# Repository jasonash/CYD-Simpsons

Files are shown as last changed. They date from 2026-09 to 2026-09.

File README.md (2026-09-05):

# CYD-Simpsons

Turn a Cheap Yellow Display (ESP32-2432S028R) into a tiny, always-on retro
television that plays The Simpsons from a microSD card.

It is deliberately TV-like, not media-player-like: you turn it on and something
is already playing. Tap to change the channel with a burst of static. A
randomizer decides what airs. Fake commercials and interference are planned.

You supply your own legally obtained episodes. This project ships no media.

## Status

Phase 0 (feasibility spike). Bring-up firmware and a converter exist; real-time
playback is not implemented yet. See `firmware/README.md`.

## Hardware

- ESP32-2432S028R "CYD": ESP32-WROOM-32, 2.8" ILI9341 320x240, XPT2046 touch, microSD, speaker header. No PSRAM, which shapes the whole design.
- microSD card, A1 class recommended, FAT32.
- Small speaker on the onboard amp header.

## Layout

```
firmware/    PlatformIO project for the ESP32
converter/   Python + ffmpeg tool that makes playable AVI files
tools/       Test media generator, helper scripts
```

## Wiring

See `firmware/WIRING.md` for the external I2S amplifier, speaker, power and
touch pins.

## Quick start

1. `cd firmware && pio run -t upload && pio device monitor` to flash the bring-up sketch.
2. `tools/make_test_media.sh 30` to generate a test clip, copy it to the SD root.
3. `converter/cyd_convert.py --out /Volumes/SD/ episodes/` to convert real episodes.
   Sources are scaled to fill the screen and centre-cropped by default
   (`--fit cover`); pass `--fit contain` for letterbox/pillarbox instead.

## Media format

MJPEG video (320x240, 15 fps by default) with 16-bit mono PCM audio in an AVI
container. Roughly 230 MB per 22 minute episode.

## License

Apache 2.0. See LICENSE.

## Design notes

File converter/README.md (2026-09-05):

# CYD-Simpsons converter

Desktop-side tool that transcodes episodes into the only format the ESP32 can
play in real time: MJPEG video + 16-bit mono PCM audio in an AVI.

Requires ffmpeg and ffprobe (`brew install ffmpeg`). Python 3.10+, no other dependencies.

```sh
./cyd_convert.py --preset balanced --out /Volumes/SDCARD/channels/1 ~/Videos/Simpsons/S05/
```

| Preset | Video | Audio | Use |
|---|---|---|---|
| quality  | 320x240 @ 20 fps, q8 | 22050 Hz | Smoothest; about 1% dropped frames in busy scenes |
| balanced | 320x240 @ 15 fps, q8 | 22050 Hz | Default. Fills the panel with decode headroom |
| smallest | 320x240 @ 15 fps, q12  | 22050 Hz | Smaller files, softer picture |

All presets fill the 320x240 panel. Sources are scaled to cover the canvas and
centre-cropped by default (`--fit cover`); `--fit contain` letterboxes instead.
`--fps N` and `--qscale N` override a preset. Each output gets a `.json`
sidecar with duration, frame count, size, and average bitrate.

Expect roughly 10 MB per minute at the default preset (a 22 minute episode is
about 230 MB).

Use `--dry-run` to print the ffmpeg commands without running them.

Planned (later phases): per-frame size clamp, seek tables, library manifest,
full SD card layout builder.

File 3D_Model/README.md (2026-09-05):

# Simpsons TV enclosure (OpenSCAD)

A cartoon-accurate television case for the CYD-Simpsons player. Parametric OpenSCAD
source, one STL per printed part, one color per part.

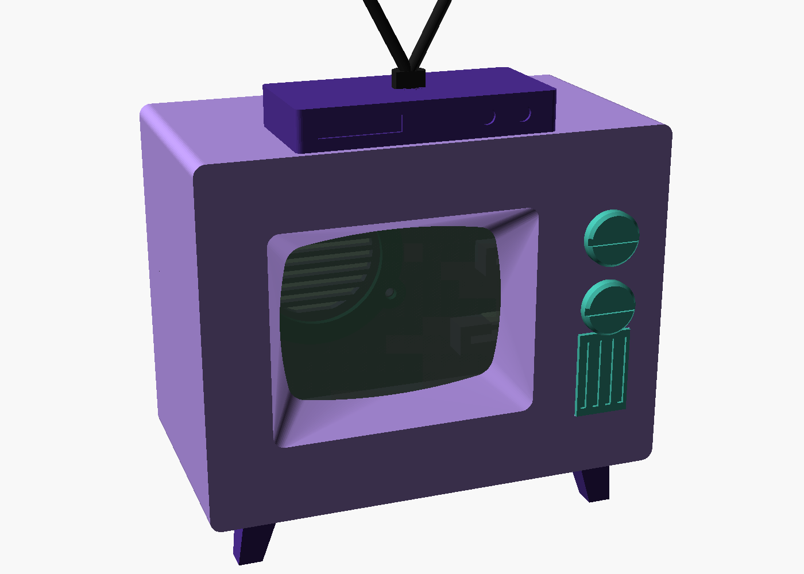
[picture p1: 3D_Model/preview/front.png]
front

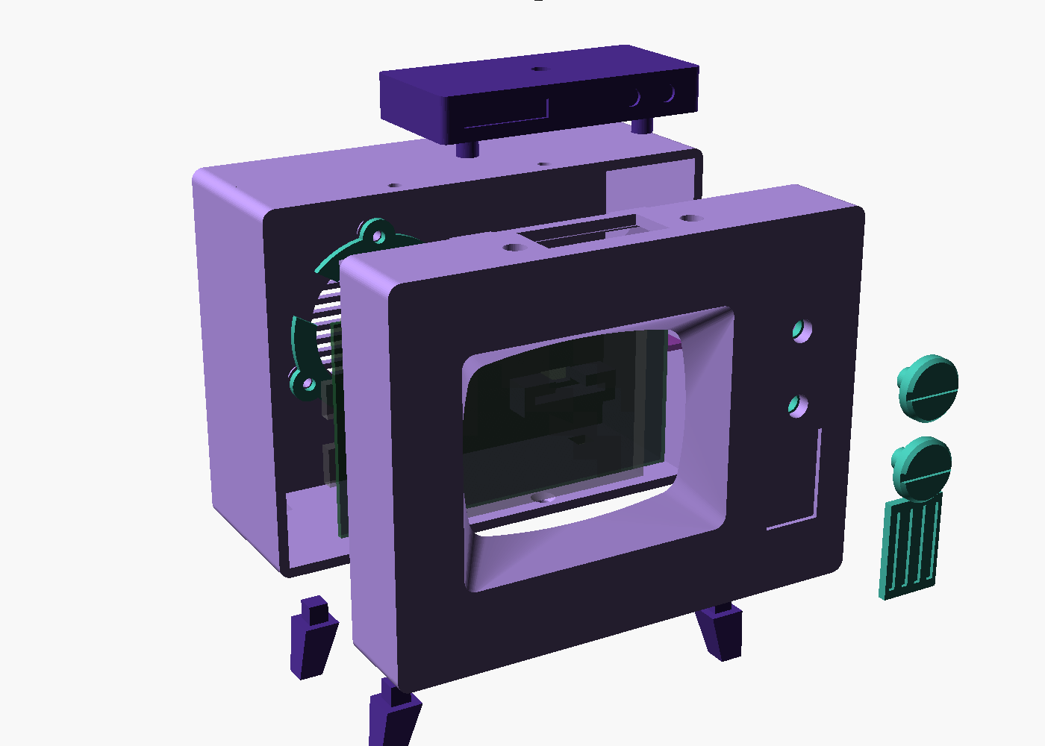
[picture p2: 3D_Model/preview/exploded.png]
exploded


## Files

| File | Purpose |
|---|---|
| `simpsons_tv.scad` | The whole model. All dimensions are parameters at the top. |
| `export.sh` | Renders every part to `stl/` and refreshes `preview/`. |
| `stl/*.stl` | Print-ready parts, already in print orientation. |
| `preview/*.png` | Assembly renders. |

Render one part by hand:

```bash
/Applications/OpenSCAD-2021.01.app/Contents/MacOS/OpenSCAD -D 'part="knob"' -o stl/knob.stl simpsons_tv.scad
```

Open `simpsons_tv.scad` in OpenSCAD for the assembly view. The variables at the top
of the file control it (Window > Customizer shows them as checkboxes and sliders,
then press F5):

- `explode = 20` pulls the assembly apart.
- `show_front_shell`, `show_rear_shell`, `show_knobs`, `show_grill`, `show_legs`,
  `show_set_top_box`, `show_speaker_clamp`, `show_components` hide parts.
- `cut_x = 60` slices the model to show a section through the middle. `cut_y` and
  `cut_z` do the same on the other axes. `-1` turns a cut off.
- `part = "plate"` shows every part in print orientation.
- `export.sh` runs `check_stl.py` on every STL it writes and fails if any part is not
  a single closed shell. Run it by hand on any STL to find floating geometry: it lists
  each disconnected shell with its bounding box in print coordinates.

## Parts and colors

| STL | Qty | Color | Print orientation | Notes |
|---|---|---|---|---|
| `front_shell` | 1 | lavender, bezel painted dark purple | face down | No supports. The screen bezel is part of the shell: a pocket that lofts from a rectangular opening at the face down to a CRT-shaped window, painted after printing. Holds the CYD, the button carrier and the grill. The lip and screw tabs grow from a chamfered step inside the wall. |
| `rear_shell` | 1 | lavender | back panel down | No supports. Speaker vents, speaker bosses, amp and USB pockets, USB-C opening. |
| `knob` | 2 | teal or green | face down | Groove across the face is the cartoon indicator bar. |
| `knob_keeper` | 2 | any | flat | Press or glue onto the knob stem behind the front plate. |
| `button_carrier` | 1 | any | flat | Carries the two 6 x 6 mm tactile switches. |
| `grill` | 1 | teal | slots up | Decorative. Glue into the front recess. |
| `leg_l`, `leg_r` | 2 each | dark purple | on its side | Square pegs into the floor. Glue. |
| `set_top_box` | 1 | dark purple | upside down | Pegs into the roof. Not glued: it covers the microSD hatch and the two roof screws. |
| `antenna` | 1 | black | flat back down | Pegs into the top of the set-top box. |
| `speaker_clamp` | 1 | any | flat | C-ring that holds the speaker flange against the back panel. |

Cartoon colors: the body is lavender purple, the screen bezel is a very dark
purple, the legs and set-top box a deeper purple, the knobs and grill teal-green,
the antenna black. Hex values used in the preview are listed at the top of the SCAD.

The bezel is painted, not printed separately: mask along the crease where the flat
face meets the slope and paint the sloped pocket dark. The other community builds
of this TV do the same.

## Hardware

All screws are M3, driven into printed 3.0 mm pilot holes (self-tapping into PLA or PETG).
Printed holes come out undersize, so 3.0 mm in the model is what an M3 actually taps
into; the first print at 2.5 mm snapped a standoff off the plate when the screw went in.
Every standoff and boss is 7 mm across with a flared base for the same reason.

| Use | Qty | Screw |
|---|---|---|
| CYD to front shell standoffs | 4 | M3 x 6 pan head |
| Button carrier to front shell | 2 | M3 x 6 pan head |
| Rear shell to front shell tabs (roof and floor) | 4 | M3 x 6 or x 8 countersunk |
| Speaker clamp | 3 | M3 x 6 pan head |

Other parts: 2 x 6 x 6 x 5 mm through-hole tactile switches, the 40 mm speaker,
the PAM8302 amp, the USB-C breakout, wire, and a little CA glue.

## Layout

- Front 118 x 90 mm, body 65 mm deep, legs add 14 mm. Aspect ratio follows the cartoon.
- The CYD is mounted with its USB ports on the left and the microSD slot on the top
  edge, i.e. rotated 180 degrees from the usual drawing. The firmware must use display
  rotation 3 instead of 1 (and the touch map flips with it).
- The microSD card is reached through a hatch in the roof, hidden by the set-top box.
- The speaker fires rearward through vents in the back panel. The front grill is decorative.
- The USB-C breakout (22 x 17 x 2 mm, connector on the long edge) sits in a slide-in
  pocket on the back panel with its port through the panel. Wire VBUS and GND to the
  CYD's 5 V and GND pins. Power only.
- The window is positioned from the CYD, not the other way round: the board sits
  `cyd_wall_gap` from the left wall and the window centre is `cyd_screen_cx` to the
  right of the board edge. Changing the screen offset moves the window, never the board.
- The window is the old-television outline: `win_w` x `win_h` (57 x 43) measured at
  the middle of each edge, every edge bowing outward by `win_bulge` (2.5) past the
  corner line, corners rounded `win_r` (5). It is cut to the panel's active picture
  area, not to the 69 x 50 glass, so the glass, its driver strip and the module edge
  all sit behind the bezel, and a small centring error hides a sliver of picture
  instead of showing the edge of the module. The picture's own corners are clipped a
  little by the bulge, which is how a CRT looked.
- The opening at the face is a plain rectangle (`bez_inset` 5 outside the window at
  the edge middles, corner radius `bez_r` 3). The pocket is a loft between the two
  outlines, `bez_slope` (10) deep, so it is steep along the edges (63 degrees) and
  sweeps out shallow at the corners (about 40 degrees, the shallowest spot of the
  face-down print; the SCAD echoes both angles). A straight tube then continues to
  `bez_depth` and stops `glass_gap` above the glass. Do not close that gap: the touch
  panel is resistive and the bezel would register as a touch.
- The amp sits in a second pocket above the USB pocket. Its own holes are only 2 mm,
  so it is held by the pocket, not screws.
- The rear shell slides over a lip on the front shell and is held by four countersunk
  M3 screws through the roof and floor into tabs on the lip. The roof screws are under
  the set-top box, the floor screws are out of sight.

## Assembly order

1. Solder the two tactile switches to the button carrier (pins through the four holes
   per switch, plungers facing the front). Wire them to CYD GPIOs.
2. Screw the CYD to the four standoffs in the front shell, screen toward the plate.
3. Screw the button carrier to its two bosses.
4. Push each knob stem through its hole from the front and press a keeper onto the stem
   from behind. Leave about 0.3 mm of play so the knob can travel. Glue the keeper.
5. Glue the grill into its recess.
6. Screw the speaker into the rear shell with the clamp ring, solder tabs in the notch.
   Slide the amp and USB breakout into their pockets and wire everything.
7. Push the rear shell onto the front shell lip and drive the four countersunk screws.
8. Glue the legs into the floor. Push the set-top box onto its roof pegs and the antenna
   into the box.

## Verify before printing the shells

These numbers came from drawings, not from measuring the actual parts. Print the small
parts first, then check these against your hardware and adjust the parameters:

- `cyd_glass` (4.5 mm): height of the CYD glass above the PCB front face. Two boards measured
  3.9 and 4.5 mm; the model uses the taller one. Sets the standoff height. Re-check on any other board.
- `cyd_screen_cx` (45.5 mm): centre of the active picture area from the board's USB
  edge. Measured on the board 2026-09-05: 16 mm of bezel on the USB side, 59 mm of
  picture, 11 mm on the far side (the earlier gap test on the first print gave 45.9,
  within 0.4 mm). `cyd_screen_cz` does the same vertically; measured centred, 2.5 mm
  top and bottom. The glass itself runs from 8 to 77 mm on the board (`cyd_glass_x0`).
- `usb_pcb_w`, `usb_pcb_l`, `usb_pcb_t`, `usb_conn_h`, `usb_conn_stick`: the USB-C
  breakout, measured 2026-09-04 as 22 x 17 x 2.0 mm, 5.0 mm overall, connector
  overhanging the edge by 1.5 mm. The connector body rides on the PCB, so the port
  opening is cut the full depth of the pocket's top rail.
- `spk_notch_angle` (150 degrees): rotate the speaker so its solder tabs sit in the
  clamp notch. The three bosses are 120 degrees apart, so any orientation works.
- Tactile switch height `sw_h` (5.0 mm). The switch travel is about 0.25 mm, and the knob
  stem rests on the plunger with 0.1 mm of pretravel.

The reference STEP file in `reference_materials/` is for the 3.5-inch CYD (ER-TFT035),
not the 2.8-inch board this project uses, so it was not used for dimensions.

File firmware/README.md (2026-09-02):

# CYD-Simpsons firmware

PlatformIO project targeting the ESP32-2432S028R Cheap Yellow Display.

## Build and flash

Install the PlatformIO CLI (`pipx install platformio`) or the VS Code extension, then:

```sh
cd firmware
pio run -e cyd_2432s028r -t upload
pio device monitor
```

If the screen stays white or colors are wrong, try the ST7789 clone profile:

```sh
pio run -e cyd_2432s028r_st7789 -t upload
```

## Layout

```
src/
  main.cpp        Phase 0 bring-up sketch (display, SD benchmark, touch, DAC tone)
  boards/         Board profiles. All GPIO numbers live here.
  player/         AVI parse, JPEG strip decode, A/V sync      (Phase 0/1)
  channels/       Scheduler, shuffle bag, broadcast position   (Phase 1/2)
  effects/        Static, fuzz, channel OSD                    (Phase 1/3)
  web/            HTTP server, JSON API, embedded assets       (Phase 4)
```

## Phase 0 bring-up sketch

On boot the sketch shows color bars, then prints a report to the display and serial:

- CPU speed, free heap, largest allocatable block, PSRAM (expect 0)
- SD mount status, card size, first few root entries
- Sustained sequential read speed (reads `/bench.bin` if present, else the largest root file)
- A 440 Hz tone through the speaker
- Touch coordinates drawn as dots and printed over serial

Record the SD MB/s and heap numbers in the project status doc. They set the media bitrate budget.

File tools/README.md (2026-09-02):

# Tools

- `make_test_media.sh` generates a synthetic test AVI (frame counter overlay, 440 Hz tone) in the playback format. Copy it to the SD card root as `bench.bin` or any `.avi` for the Phase 0 spike.

Planned: flashing helper, SD card layout checker.

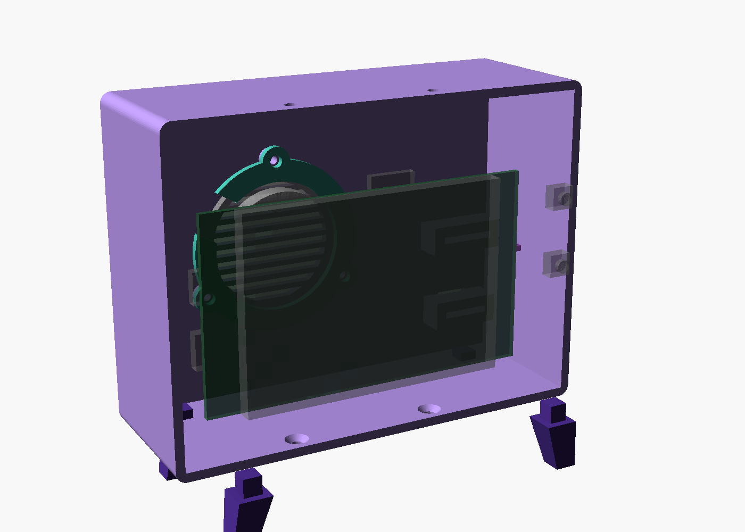
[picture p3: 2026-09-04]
3D_Model/preview/inside_rear.png

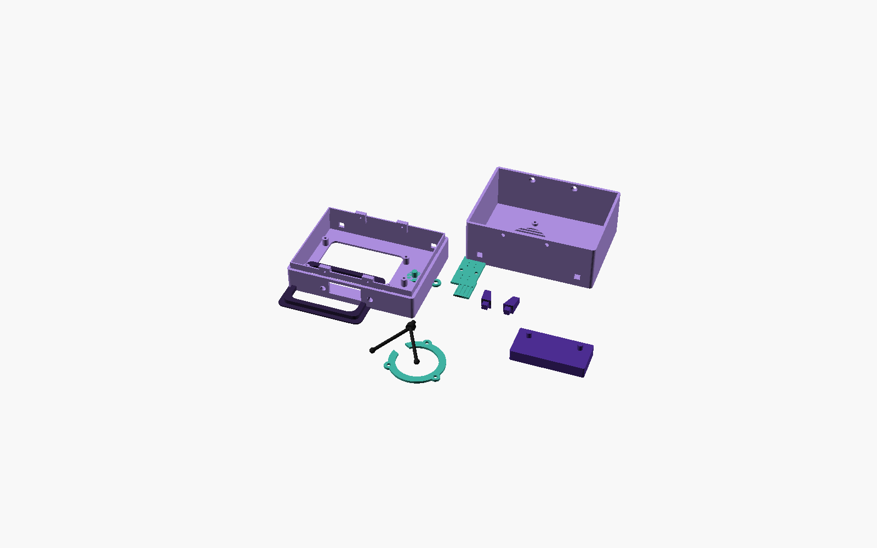
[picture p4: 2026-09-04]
3D_Model/preview/plate.png

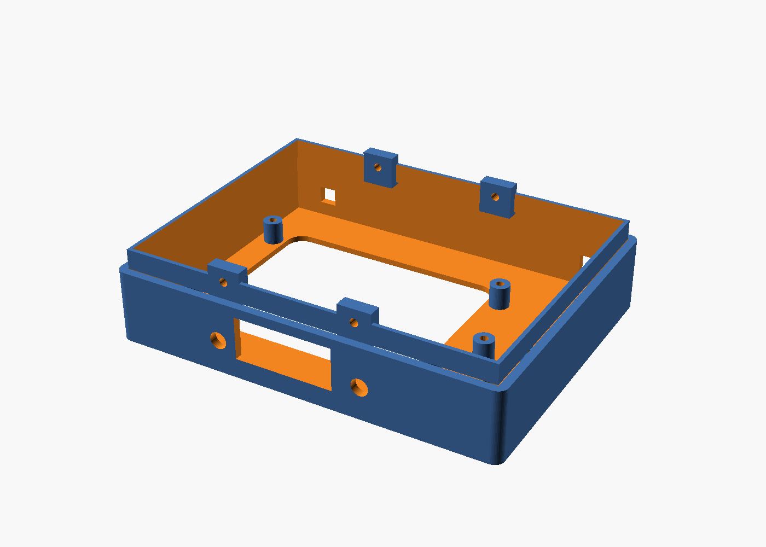
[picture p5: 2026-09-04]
3D_Model/preview/front_shell_inside.png

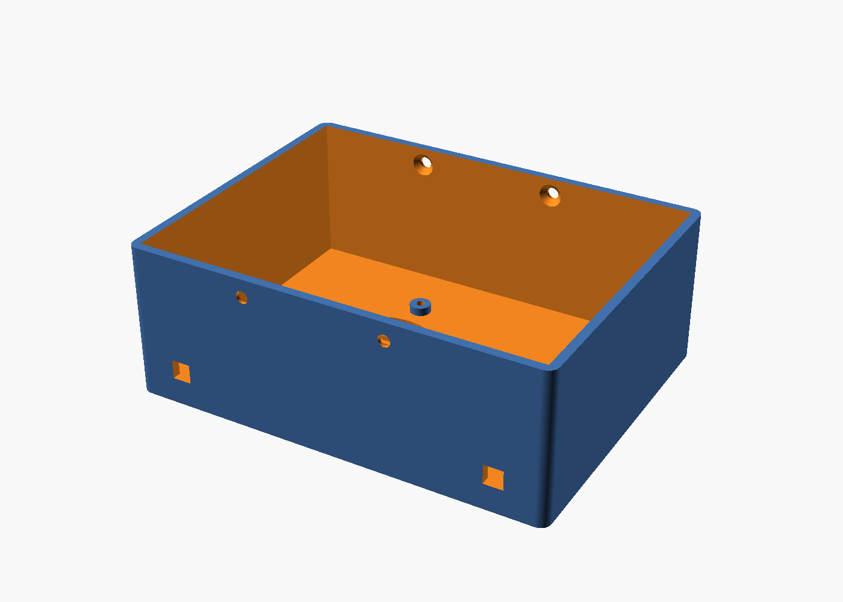
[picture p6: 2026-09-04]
3D_Model/preview/rear_shell_inside.png

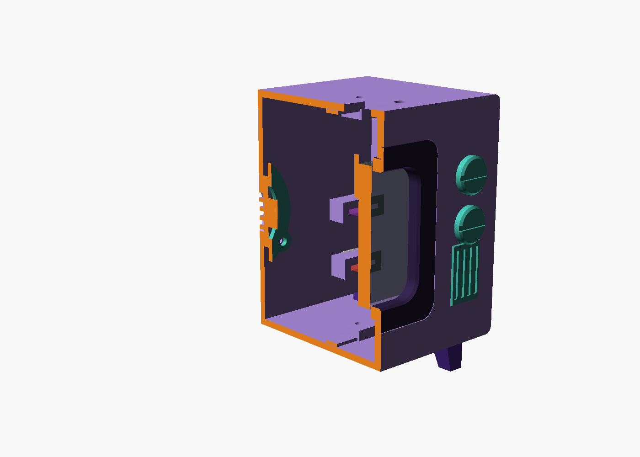
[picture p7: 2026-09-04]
3D_Model/preview/cutaway.png

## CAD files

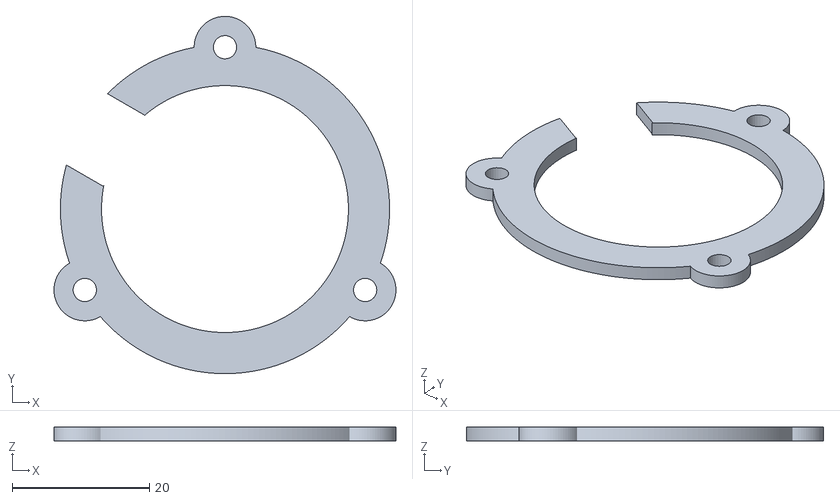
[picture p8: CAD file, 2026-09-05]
3D_Model/stl/speaker_clamp.stl
49.9 x 52.1 x 2.00

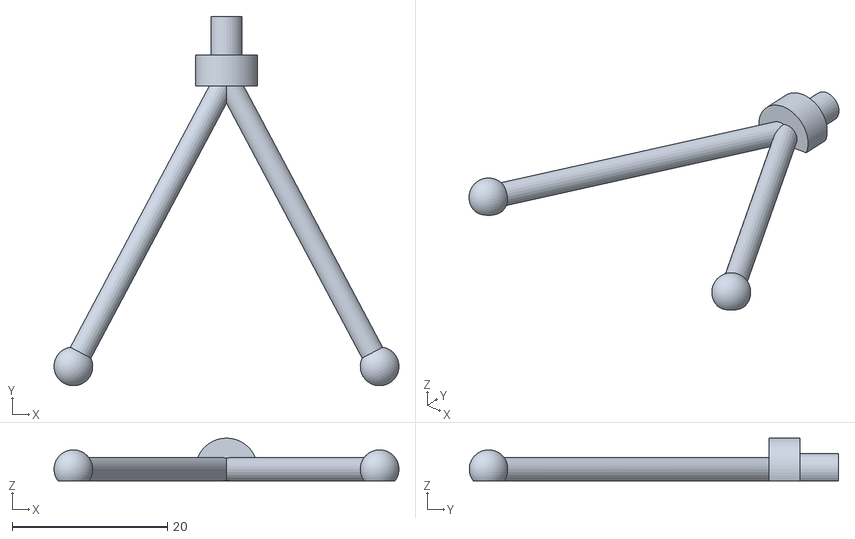
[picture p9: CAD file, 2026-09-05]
3D_Model/stl/antenna.stl
44.4 x 47.6 x 5.50

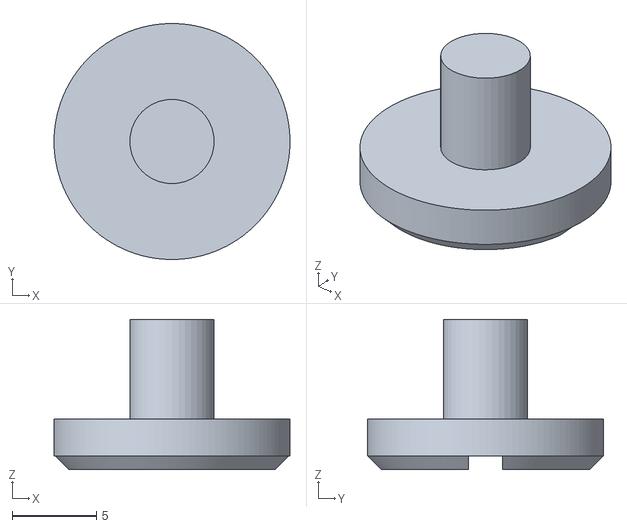
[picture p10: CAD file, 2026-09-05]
3D_Model/stl/knob.stl
14.0 x 14.0 x 8.90

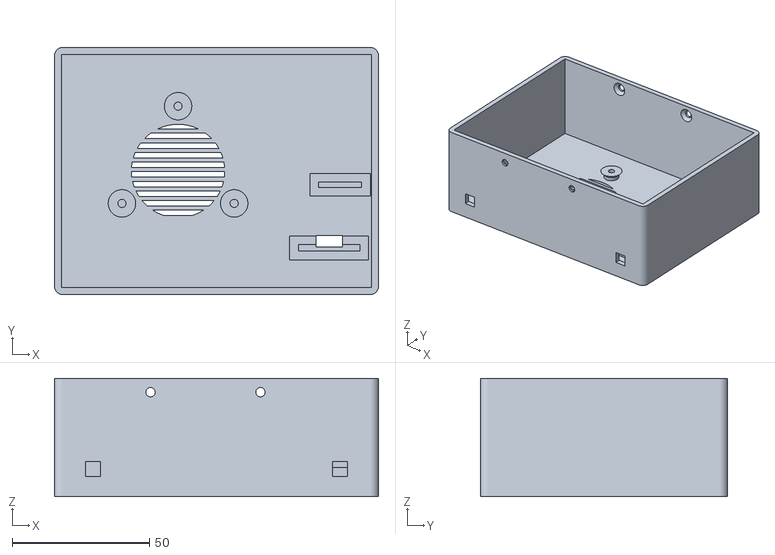
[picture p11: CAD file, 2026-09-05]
3D_Model/stl/rear_shell.stl
118.0 x 90.0 x 43.0

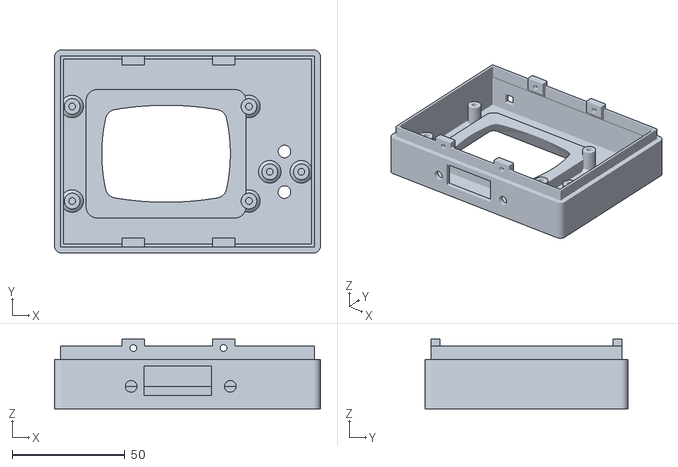
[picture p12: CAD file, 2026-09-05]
3D_Model/stl/front_shell.stl
118.0 x 90.0 x 31.0

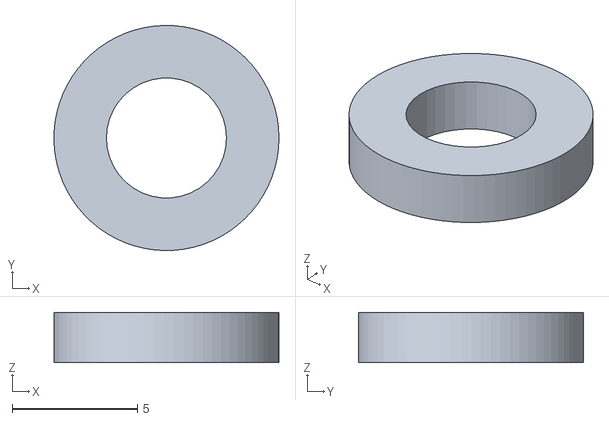
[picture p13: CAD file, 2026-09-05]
3D_Model/stl/knob_keeper.stl
9.00 x 9.00 x 2.00

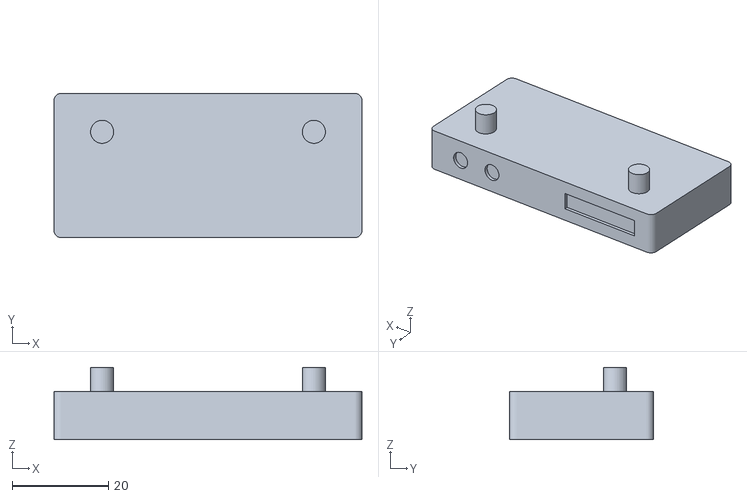
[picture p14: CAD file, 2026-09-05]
3D_Model/stl/set_top_box.stl
64.0 x 30.0 x 15.0

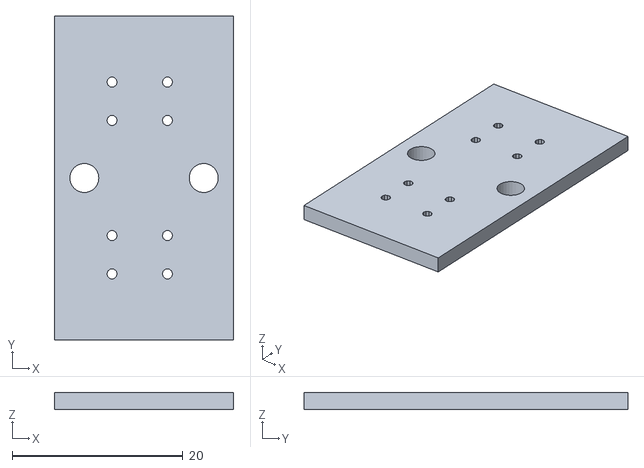
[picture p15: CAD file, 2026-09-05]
3D_Model/stl/button_carrier.stl
21.0 x 38.0 x 2.00

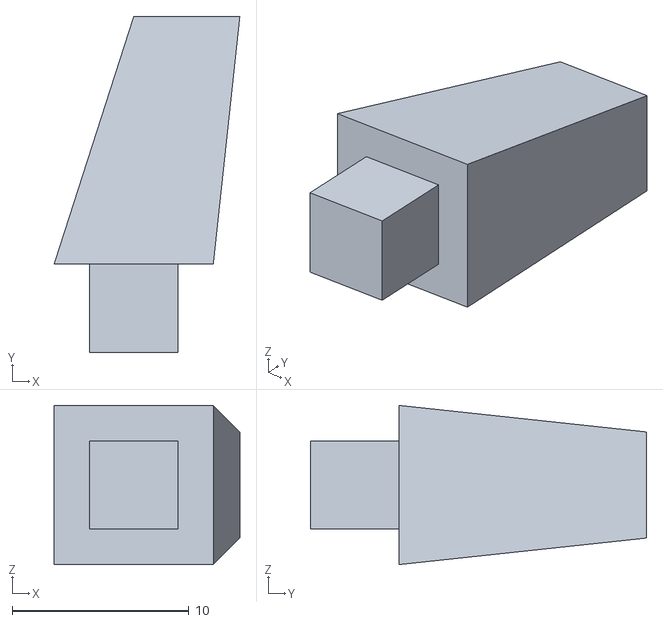
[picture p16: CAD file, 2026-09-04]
3D_Model/stl/leg_r.stl
10.5 x 19.0 x 9.00

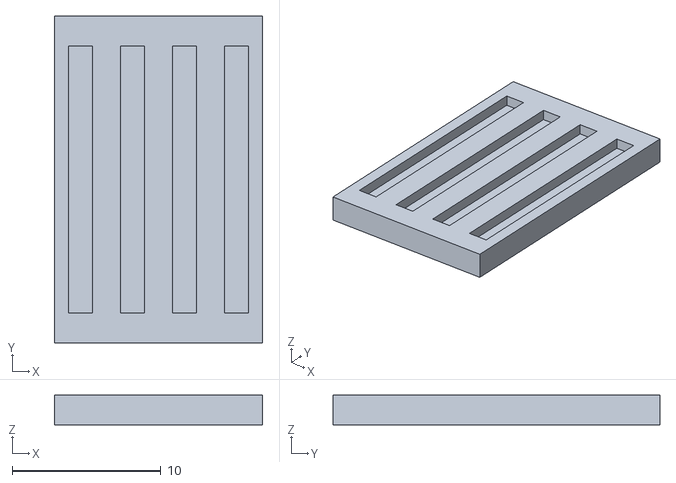
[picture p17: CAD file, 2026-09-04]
3D_Model/stl/grill.stl
14.0 x 22.0 x 2.00

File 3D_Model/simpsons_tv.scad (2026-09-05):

// CYD-Simpsons: cartoon television enclosure for the ESP32-2432S028R (2.8" CYD)
//
// Coordinate system (assembly): X = width (viewer's left to right), Y = depth
// (front face at y=0, rear at y=D), Z = height (table at z=0, legs below it).
//
// Every printable part is a module in its own local coordinates; assembly()
// places them. export(name) re-orients each part for printing. Render one
// part with:  openscad -D 'part="front_shell"' -o front_shell.stl simpsons_tv.scad
//
// All dimensions in mm.

part = "assembly";          // see export() for names
explode = 0;                // [0:1:40] assembly explode distance (0 = assembled)

/* [Assembly view: what to show] */
show_components = true;     // ghost the electronics
show_front_shell = true;
show_rear_shell = true;
show_knobs = true;          // knobs, keepers and the button carrier
show_grill = true;
show_legs = true;
show_set_top_box = true;    // box and antenna
show_speaker_clamp = true;

/* [Assembly view: cutaway] */
// Remove everything below the plane. -1 = off. Try cut_x = 60 for a section
// through the middle, or cut_y = 30 to look into the rear shell from the front.
cut_x = -1;                 // [-1:1:118]
cut_y = -1;                 // [-1:1:65]
cut_z = -1;                 // [-1:1:110]

$fa = 2; $fs = 0.4;
EPS = 0.01;

/* ---------- Colors (print colors, see README) ---------- */
C_FRONT  = "#A98BDA";   // lavender: front shell, rear shell
C_DARK   = "#2E2145";   // dark purple: painted bezel (part of the front shell)
C_LEG    = "#4B2C8F";   // purple: legs, set-top box
C_TEAL   = "#3FB0A0";   // teal: knobs, grill
C_BLACK  = "#1E1E1E";   // antenna
C_PCB    = "#2C6B3F";
C_METAL  = "#B0B0B0";
C_GHOST  = [0.5, 0.5, 0.5, 0.35];

/* ---------- Overall envelope ---------- */
W = 118;            // width
H = 90;             // height (body only, legs extra)
D = 65;             // depth
wall = 2.5;         // side/roof/floor wall thickness
plate_t = 3;        // front plate thickness
split_y = 22;       // front shell / rear shell joint
edge_r = 3;         // radius on the front-to-back edges
fit = 0.2;          // clearance per side for mating parts

/* ---------- Shell joint ---------- */
lip_len = 6;        // lip on the front shell that enters the rear shell
lip_t = 1.2;
lip_root = 2;       // chamfered step inside the front shell wall that carries the lip
lip_sink = 0.5;     // how far the lip and tabs reach back into that step
tab_w = 10; tab_t = 4; tab_len = 9;
tab_x = [35, 75];               // screw positions, hidden under the set-top box
screw_y = split_y + 5;
pilot_m3 = 3.0; clear_m3 = 3.4; csk_d = 6.4;   // all hardware is M3. Pilots print undersize, 3.0 taps cleanly
boss_fillet = 1.5;  // flared base on every standoff and boss so it cannot snap off the plate

/* ---------- Screen bezel (one piece with the front shell, painted dark) ----------
   A sloped pocket in the front plate, like an old CRT set. The opening at the face is
   a plain rectangle with small corners; the window at the bottom is the CRT outline
   (edges bowing outward, corners rounded); the slope is a loft between the two, so it
   is flat and steep along the edges and sweeps wide at the corners, as in the cartoon.
   A short straight tube then carries the window back to just above the glass.
   The window is cut to the panel's active area (57.6 x 43.2 on the 2.8" ILI9341),
   not to the glass, so the module edge and the driver strip stay hidden. */
win_w = 57; win_h = 43;         // window extents at the middle of each edge (apex to apex); just inside
                                // the active area, so a 0.5 mm centring error hides a sliver of picture
                                // instead of showing the module edge
win_bulge = 2.5;                // how far each edge bows out past the corner line (the CRT look)
win_r = 5;                      // corner radius of the window
bez_inset = 5;                  // bezel width at the middle of each edge
bez_r = 3;                      // corner radius of the rectangular opening at the face
bez_slope = 10;                 // slope depth. The corners are the shallow spot for a face-down print:
                                // see the echo of the corner angle, keep it near 40 degrees or steeper
bez_depth = 10;                 // face to the back of the tube (>= bez_slope; the glass sits glass_gap behind it)
bez_wall = 2;                   // material outside the opening at the face
bez_w = win_w + 2*bez_inset;    // opening at the face: 67 x 53
bez_h = win_h + 2*bez_inset;
win_cz = 46;                    // window centre height. win_cx is derived from the CYD position below
// slope angle at the corners (the diagonal run is the longest): outer corner to inner corner
bez_corner_run = sqrt(2) * (bez_inset + win_bulge + (win_r - bez_r) * (sqrt(2) - 1));
bez_corner_angle = atan(bez_slope / bez_corner_run);
echo(str("bezel slope: ", round(atan(bez_slope / bez_inset)), " deg at the edges, ",
         round(bez_corner_angle), " deg at the corners (run ", round(bez_corner_run*10)/10, " mm)"));

/* ---------- CYD (ESP32-2432S028R) ----------
   Mounted with the USB ports on the LEFT and the microSD slot on the TOP edge
   (board rotated 180 degrees from the usual drawing). Firmware uses rotation 3.
   Front of the PCB faces the screen. */
cyd_w = 86.1; cyd_h = 49.9; cyd_t = 1.6;
cyd_hole_d = 3.2; cyd_hole_in_x = 3.83; cyd_hole_in_z = 3.98;
cyd_screen_cx = 45.5;           // active area centre from the board's left (USB) edge.
                                // Jason's 2026-09-05 sketch: 16 mm bezel left, 59 active, 11 right.
                                // The 2026-09-04 gap test on the first print gave 45.9; within 0.4 mm.
cyd_screen_cz = cyd_h/2;        // active area centre from the board's bottom edge (measured centred, 2.5 each side)
cyd_wall_gap = 1.5;             // board edge to the inner face of the left wall
cyd_glass_x0 = 8;               // glass module from 8 to 77 mm on the board (the left 8 mm of it is the driver strip)
cyd_glass_w = 69; cyd_glass_h = 50;
cyd_glass = 4.5;                // glass top above PCB front face. Boards measure 3.9 (junk bin) and 4.5 (new);
                                // build for the tallest, a shorter board just sits deeper behind the bezel
glass_gap = 0.5;                // gap between the bezel tube and the glass (resistive touch: do not press on it)
cyd_x0 = wall + cyd_wall_gap;   // 4. The window follows the board, never the other way round
cyd_z0 = win_cz - cyd_screen_cz;
win_cx = cyd_x0 + cyd_screen_cx;   // window centred on the measured screen centre (49.5)
cyd_y  = bez_depth + glass_gap + cyd_glass;   // PCB front face (11)
standoff_d = 7;                 // 2 mm wall around the 3.0 mm pilot
standoff_h = cyd_y - plate_t;
cyd_holes = [for (x=[cyd_hole_in_x, cyd_w-cyd_hole_in_x], z=[cyd_hole_in_z, cyd_h-cyd_hole_in_z]) [cyd_x0+x, cyd_z0+z]];
sd_cx = cyd_x0 + 50.6;          // microSD centre (board flipped)
hatch_w = 30; hatch_y0 = 6; hatch_y1 = 19;

/* ---------- Knobs (buttons) ---------- */
knob_x = 102;
knob_z = [63, 45];
knob_d = 14; knob_t = 3; knob_gap = 0.5;
knob_chamfer = 0.8;
groove_w = 2; groove_d = 0.8;
stem_d = 5; stem_hole_d = 5.6;
stem_end_y = 5.4;               // stem tip (assembly y) rests on the switch plunger
keeper_od = 9; keeper_id = 4.8; keeper_t = 2;
sw_h = 5.0;                     // 6x6 tact switch, base to plunger tip
sw_body_h = 3.5; sw_plunger_d = 3.5;
sw_pitch_x = 6.5; sw_pitch_z = 4.5; sw_pin_d = 1.2;
sw_pretravel = 0.1;
carrier_y = stem_end_y + sw_pretravel + sw_h;   // carrier front face
carrier_t = 2;
carrier_x0 = 92; carrier_x1 = 113; carrier_z0 = 35; carrier_z1 = 73;
carrier_boss = [[95.5, 54], [109.5, 54]];

/* ---------- Grill (decorative) ---------- */
grill_x0 = 95; grill_z0 = 16; grill_w = 14; grill_h = 22;
grill_t = 2; grill_recess = 1.2; grill_slots = 4; grill_slot_w = 1.6; grill_slot_d = 0.8;

/* ---------- Legs ---------- */
leg_top = 9; leg_bot = 6; leg_h = 14; leg_splay = 3;
peg = 5; peg_h = 5;
leg_pos = [[14, 10], [W-14, 10], [14, D-10], [W-14, D-10]];

/* ---------- Set-top box ---------- */
box_w = 64; box_d = 30; box_h = 10; box_r = 1.5;
box_x0 = 24; box_y0 = 2;
box_peg_d = 4.8; box_peg_h = 5;
box_pegs = [[10, 8], [54, 8]];  // local xy
ant_peg_d = 4; ant_hole_d = 4.3; ant_peg_h = 5;

/* ---------- Antenna ---------- */
rod_d = 3; rod_len = 42; rod_angle = 28; ball_d = 5; hub_d = 8; hub_h = 4;

/* ---------- Speaker (40 mm, rear firing) ---------- */
spk_d = 40.5; spk_flange_t = 3.5; spk_depth = 19; spk_magnet_d = 22;   // flange and depth measured 2026-09-04 (listing said 2.7 and 18)
spk_cx = 45; spk_cz = 45;
spk_boss_r = 23.6; spk_boss_d = 7;
spk_boss_angles = [90, 210, 330];
spk_notch_angle = 150;          // where the solder tabs sit (between bosses)
clamp_od = 48; clamp_id = 36; clamp_t = 2;
vent_d = 34; vent_slot = 2; vent_pitch = 3.5;
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

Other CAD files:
3D_Model/stl/leg_l.stl

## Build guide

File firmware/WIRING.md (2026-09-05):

# Wiring

Board: ESP32-2432S028R (2.8" CYD). Pin names refer to the ESP32 GPIO numbers
printed on the board's headers. Check the header labels on your board before
soldering; the 1.25 mm connectors vary between revisions.

## External I2S amplifier (MAX98357A), recommended

The CYD's onboard audio path (internal DAC on GPIO26 into the SC8002B amp)
picks up impulse noise from both SPI buses whenever the SD card or the
display is busy (measured 2026-09-05). An I2S amplifier bypasses that path
entirely and gives 16-bit audio.

Only GPIO22 and GPIO27 are free outputs on the headers, so the old DAC line
doubles as I2S data. The onboard amp then amplifies the data signal into its
unused speaker header, which is harmless.

| MAX98357A pin | Connect to | Notes |
|---|---|---|
| VIN | 5 V (VIN on the P1 header) | 2.5 to 5.5 V; use 5 V for full output |
| GND | GND | |
| BCLK | GPIO22 (CN1 or P3 header) | bit clock |
| LRC | GPIO27 (CN1 header) | word select |
| DIN | GPIO26 | the speaker amp input line; GPIO4 (red LED) works too, change `PIN_I2S_DOUT` in `src/boards/cyd_2432s028r.h` |
| GAIN | unconnected | 9 dB. GND = 12 dB, VIN = 6 dB, 100k to GND = 15 dB, 100k to VIN = 3 dB |
| SD | unconnected | amp enabled, (L+R)/2 output; the firmware sends the same sample on both channels |
| Speaker +/- | 4 ohm 3 W speaker | no series pot needed |

Firmware: hold the screen for the settings menu, set AUDIO OUT to I2S AMP,
exit. Takes effect at the next episode and is saved in NVS.

## Onboard speaker header (fallback)

Speaker on the 2-pin speaker header. Expect clicks and hiss that track SD
and display activity. A 50 ohm 3 W wirewound pot wired as a rheostat in the
speaker positive lead tames the level; it does not remove the noise.

## Power

5 V through the board's micro USB, or 5 V and GND on the P1 header from a
USB-C breakout mounted in the case. The board draws about 200 mA playing.

## Touch panel

XPT2046 on GPIO25 (CLK), 32 (MOSI), 39 (MISO), 33 (CS), 36 (IRQ), bit-banged.
GPIO25 is also DAC channel 1; the firmware keeps that DAC disabled, otherwise
the panel reads as permanently pressed whenever audio runs.

## Free pins

None once the I2S amp is wired. GPIO35 on the P3 header is input only (LDR or
a button). GPIO0 is the BOOT button. GPIO4, 16, 17 drive the RGB LED and can
be repurposed as outputs if the LED is not needed.

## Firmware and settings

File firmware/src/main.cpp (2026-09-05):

// CYD-Simpsons firmware entry point.
//
// Phase 1: a single channel. Scan the card for episodes, play them from a
// shuffle bag back to back, and change episode on a tap with a burst of
// static. The bring-up sketch lives in bringup.cpp and is built by the
// *_bringup envs.

#ifndef CYD_BRINGUP

#include <Arduino.h>
#include <TFT_eSPI.h>

#include "boards/board.h"
#include "effects/static_fx.h"
#include "player/player.h"
#include "player/sd_card.h"
#include "tv/input.h"
#include "tv/library.h"
#include "tv/menu.h"
#include "tv/noise_probe.h"
#include "tv/settings.h"

static TFT_eSPI tft;

// Episodes live in /episodes; a card with AVIs in the root still works.
static const char* kEpisodeDirs[] = {"/sdcard/episodes", "/sdcard"};
static const uint32_t kStaticMs = 400;

static bool s_ready = false;
static input::Event s_pending = input::NONE;   // event that stopped playback

static void setLed(bool r, bool g, bool b) {
    digitalWrite(PIN_LED_R, r ? LED_ON : LED_OFF);
    digitalWrite(PIN_LED_G, g ? LED_ON : LED_OFF);
    digitalWrite(PIN_LED_B, b ? LED_ON : LED_OFF);
}

static void showMessage(const char* line1, const char* line2) {
    tft.fillScreen(TFT_BLACK);
    tft.setTextColor(TFT_YELLOW, TFT_BLACK);
    tft.drawString(line1, 8, 100, 4);
    tft.setTextColor(TFT_WHITE, TFT_BLACK);
    tft.drawString(line2, 8, 130, 2);
}

// Called by the player once per frame. A tap ends the episode; a hold opens
// the settings menu.
static bool stopOnInput() {
    input::Event ev = input::poll();
    if (ev == input::NONE) return false;
    s_pending = ev;
    return true;
}

void setup() {
    Serial.begin(115200);
    delay(300);
    Serial.println("\nCYD-Simpsons");

    pinMode(PIN_LED_R, OUTPUT);
    pinMode(PIN_LED_G, OUTPUT);
    pinMode(PIN_LED_B, OUTPUT);
    setLed(true, false, false);

    tft.init();
    settings::load();
    settings::apply(&tft);
    tft.fillScreen(TFT_BLACK);
    if (!player::initDisplayDma(&tft)) Serial.println("Display DMA unavailable");

    Serial.printf("Heap: %u free, %u largest block\n",
                  (unsigned)ESP.getFreeHeap(), (unsigned)ESP.getMaxAllocHeap());

    // The card must be initialised by the IDF driver before anything else
    // touches the SPI bus (see sd_card.h).
    if (!sdcard::mount()) {
        showMessage("No SD card", "Insert a FAT32 card and reset");
        setLed(false, false, true);
        return;
    }
    Serial.printf("SD: %u MB at %u kHz\n", (unsigned)sdcard::capacityMB(),
                  (unsigned)sdcard::busKHz());

    for (const char* dir : kEpisodeDirs) {
        if (library::scan(dir) > 0) break;
    }
    if (library::count() == 0) {
        showMessage("No episodes", "Put .avi files in /episodes on the card");
        setLed(true, false, false);
        return;
    }

    player::begin(&tft);
    input::begin();
    input::setFlipped(settings::values().flip);

    // Fallback if the menu is unreadable (wrong panel variant): hold the
    // screen during boot to flip the colours.
    delay(150);
    if (input::pressed()) {
        settings::values().invert = !settings::values().invert;
        settings::save();
        tft.invertDisplay(settings::values().invert);
        showMessage("Colours flipped", "Release the screen");
        Serial.println("Boot touch: colours flipped");
        while (input::pressed()) delay(20);
        input::flush();
        tft.fillScreen(TFT_BLACK);
    }

    setLed(false, true, false);
    s_ready = true;
}

void loop() {
    if (!s_ready) {
        delay(1000);
        return;
    }
    const char* path = library::next();
    tft.invertDisplay(settings::values().invert);
    Serial.printf("Playing %s\n", library::currentName());
    if (!player::play(path, 100, stopOnInput)) {
        showMessage("Cannot play", library::currentName());
        setLed(true, false, false);
        delay(3000);
        setLed(false, true, false);
        return;
    }
    if (player::wasStopped()) {
        if (s_pending == input::PROBE) {
            s_pending = input::NONE;
            probe::run(&tft, library::current());
            input::flush();
            return;
        }
        if (s_pending == input::HOLD) {
            s_pending = input::NONE;
            Serial.println("Input: hold, settings menu");
            menu::run(&tft);
            input::setFlipped(settings::values().flip);
            return;
        }
        Serial.println("Input: tap, changing episode");
        s_pending = input::NONE;
        fx::tvStatic(&tft, kStaticMs);
        input::flush();
    }
}

#endif  // CYD_BRINGUP

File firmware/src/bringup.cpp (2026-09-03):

// CYD-Simpsons: Phase 0 bring-up and measurement sketch.
//
// Goal: prove each subsystem works on this exact board and collect the numbers
// the design depends on (SD throughput, free RAM). Results print over serial at
// 115200 and are summarized on the display.
//
// Once numbers are recorded in docs/PROJECT_STATUS.md, this file becomes the
// real firmware entry point and the checks move into a diagnostics mode.

#ifdef CYD_BRINGUP
// Built only by the *_bringup envs. The player entry point is main.cpp.

#include <Arduino.h>
#include <SPI.h>
#include <SD.h>
#include <TFT_eSPI.h>
#include <XPT2046_Bitbang.h>
#include <fcntl.h>
#include <unistd.h>
#include "esp_vfs_fat.h"
#include "driver/sdspi_host.h"
#include "driver/spi_common.h"
#include "sdmmc_cmd.h"

#include "boards/board.h"

static TFT_eSPI tft;
static SPIClass sdSpi(VSPI);
static XPT2046_Bitbang touch(PIN_TOUCH_MOSI, PIN_TOUCH_MISO, PIN_TOUCH_CLK, PIN_TOUCH_CS);

static bool sdOk = false;
static float sdMBps = 0.0f;
static uint16_t lineY = 0;

// ---------------------------------------------------------------------------
// Helpers
// ---------------------------------------------------------------------------
static void logLine(const char *fmt, ...) {
    char buf[128];
    va_list args;
    va_start(args, fmt);
    vsnprintf(buf, sizeof(buf), fmt, args);
    va_end(args);

    Serial.println(buf);
    if (lineY < DISPLAY_H - 10) {
        tft.drawString(buf, 4, lineY, 2);
        lineY += 16;
    }
}

static void setLed(bool r, bool g, bool b) {
    digitalWrite(PIN_LED_R, r ? LED_ON : LED_OFF);
    digitalWrite(PIN_LED_G, g ? LED_ON : LED_OFF);
    digitalWrite(PIN_LED_B, b ? LED_ON : LED_OFF);
}

// ---------------------------------------------------------------------------
// Subsystem checks
// ---------------------------------------------------------------------------
static void checkDisplay() {
    tft.init();
    tft.setRotation(TFT_ROTATION);

    // Color bars: instantly shows wrong driver, wrong RGB order, or inversion.
    const uint16_t bars[] = {TFT_WHITE, TFT_YELLOW, TFT_CYAN, TFT_GREEN,
                             TFT_MAGENTA, TFT_RED, TFT_BLUE, TFT_BLACK};
    const int barW = DISPLAY_W / 8;
    for (int i = 0; i < 8; i++) {
        tft.fillRect(i * barW, 0, barW, DISPLAY_H, bars[i]);
    }
    delay(5000);

    tft.fillScreen(TFT_BLACK);
    tft.setTextColor(TFT_GREEN, TFT_BLACK);
    lineY = 4;
}

static void checkSd() {
    sdSpi.begin(PIN_SD_SCK, PIN_SD_MISO, PIN_SD_MOSI, PIN_SD_CS);
    sdOk = SD.begin(PIN_SD_CS, sdSpi, SD_SPI_HZ);
    if (!sdOk) {
        logLine("SD: mount FAILED");
        return;
    }

    uint64_t sizeMB = SD.cardSize() / (1024ULL * 1024ULL);
    logLine("SD: mounted, %llu MB, type %d", sizeMB, (int)SD.cardType());

    // List the root so we know the card layout is what we think it is.
    File root = SD.open("/");
    int count = 0;
    for (File f = root.openNextFile(); f && count < 6; f = root.openNextFile()) {
        logLine("  %s %s (%u KB)", f.isDirectory() ? "[D]" : "   ", f.name(),
                (unsigned)(f.size() / 1024));
        count++;
    }
    root.close();
}

// Sustained sequential read benchmark. Reads the largest file in the root
// (or /bench.bin if present) in 4 KB chunks for up to 8 MB. This is the number
// that caps total media bitrate.
// Second opinion: the ESP-IDF sdspi host driver, which the Arduino SD library
// sits beside (not on top of). It uses DMA transactions and multi-block
// reads without byte-at-a-time polling, and is not clamped to 25 MHz. This
// tears down the Arduino SD mount and re-mounts the card at /sdcard.
static void benchSdIdf() {
    if (sdOk) {
        SD.end();
        sdSpi.end();
    }

    sdmmc_host_t host = SDSPI_HOST_DEFAULT();
    host.slot = VSPI_HOST;
    host.max_freq_khz = SD_SPI_HZ / 1000;

    spi_bus_config_t bus = {};
    bus.mosi_io_num = PIN_SD_MOSI;
    bus.miso_io_num = PIN_SD_MISO;
    bus.sclk_io_num = PIN_SD_SCK;
    bus.quadwp_io_num = -1;
    bus.quadhd_io_num = -1;
    bus.max_transfer_sz = 16384;
    esp_err_t err = spi_bus_initialize(VSPI_HOST, &bus, SPI_DMA_CH_AUTO);
    if (err != ESP_OK) {
        logLine("IDF sdspi: bus init failed 0x%x", err);
        return;
    }

    sdspi_device_config_t slot = SDSPI_DEVICE_CONFIG_DEFAULT();
    slot.gpio_cs = (gpio_num_t)PIN_SD_CS;
    slot.host_id = VSPI_HOST;

    esp_vfs_fat_sdmmc_mount_config_t mnt = {};
    mnt.format_if_mount_failed = false;
    mnt.max_files = 4;
    mnt.allocation_unit_size = 16 * 1024;

    sdmmc_card_t* card = nullptr;
    err = esp_vfs_fat_sdspi_mount("/sdcard", &host, &slot, &mnt, &card);
    if (err != ESP_OK) {
        logLine("IDF sdspi: mount failed 0x%x", err);
        spi_bus_free(VSPI_HOST);
        return;
    }
    logLine("IDF sdspi: mounted at %u kHz, %s", (unsigned)card->max_freq_khz,
            card->cid.name);

    static uint8_t buf[16384];
    const size_t limit = 8UL * 1024UL * 1024UL;

    int fd = open("/sdcard/bench.bin", O_RDONLY);
    if (fd >= 0) {
        size_t total = 0;
        uint32_t t0 = millis();
        while (total < limit) {
            int n = read(fd, buf, sizeof(buf));
            if (n <= 0) break;
            total += n;
        }
        uint32_t dt = millis() - t0;
        close(fd);
        float mbps = dt > 0 ? (total / 1048576.0f) / (dt / 1000.0f) : 0.0f;
        logLine("IDF bench posix16K: %u KB in %u ms = %.2f MB/s",
                (unsigned)(total / 1024), (unsigned)dt, mbps);
    } else {
        logLine("IDF bench: open failed");
    }

    // Raw multi-sector reads, 32 sectors (16 KB) per command, 2 MB total.
    {
        const uint32_t per = 32, nSect = 4096;
        uint32_t ok = 0;
        uint32_t t0 = millis();
        for (uint32_t sct = 2048; sct < 2048 + nSect; sct += per) {
            if (sdmmc_read_sectors(card, buf, sct, per) == ESP_OK) ok += per;
        }
        uint32_t dt = millis() - t0;
        float mbps = dt > 0 ? (ok * 512 / 1048576.0f) / (dt / 1000.0f) : 0.0f;
        logLine("IDF bench raw16K: %u sectors in %u ms = %.2f MB/s",
                (unsigned)ok, (unsigned)dt, mbps);
    }

    // Force the bus to 40 MHz (the driver stops at 20 MHz in SPI mode) and
    // repeat the raw read. Tells us whether the wire clock is the ceiling.
    if (sdspi_host_set_card_clk((sdspi_dev_handle_t)card->host.slot, 40000) == ESP_OK) {
        const uint32_t per = 32, nSect = 4096;
        uint32_t ok = 0;
        uint32_t t0 = millis();
        for (uint32_t sct = 2048; sct < 2048 + nSect; sct += per) {
            if (sdmmc_read_sectors(card, buf, sct, per) == ESP_OK) ok += per;
        }
        uint32_t dt = millis() - t0;
        float mbps = dt > 0 ? (ok * 512 / 1048576.0f) / (dt / 1000.0f) : 0.0f;
        logLine("IDF bench raw16K@40MHz: %u/%u sectors in %u ms = %.2f MB/s",
                (unsigned)ok, (unsigned)nSect, (unsigned)dt, mbps);
    } else {
        logLine("IDF bench: set 40 MHz failed");
    }
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

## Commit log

2026-09-02 [Feature] Scaffold Phase 0: PlatformIO firmware, board profile, bring-up sketch, converter
2026-09-03 [Fix] Hold color bars 5 s and skip drawtext when ffmpeg lacks it
    [main.cpp]
2026-09-03 [Feature] Benchmark IDF sdspi driver vs Arduino SD, POSIX and raw sector reads
2026-09-03 [Feature] Phase 0 player spike: AVI reader, JPEGDEC strip decode, DAC audio, A/V sync
    - player/sd_card: IDF sdspi mount on VSPI forced to 40 MHz, with bit-banged
    CMD12/CMD0 recovery so a soft reset mid-read does not wedge the card
    - player/avi_reader: buffered RIFF/AVI walker (hdrl, movi, JUNK, ix##, rec,
    AVIX continuation)
    - player/audio_out: I2S built-in DAC on GPIO26 with APLL clock (PLL_D2 runs
    5.4x fast at 8/16 kHz), primed DMA ring, descriptor-count master clock,
    underrun detection
    - player/player: reader task on core 0 feeds audio and a 4-slot frame ring;
    decoder on core 1 presents frames on the audio clock, drops when >1 frame
    late; per-window stats over serial
    - main.cpp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
    [audio_out.cpp, avi_reader.h, bringup.cpp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]
2026-09-03 [Fix] Correct RGB565 byte order for pushImage; spike prefers 1.avi on the card
    [main.cpp, player.cpp]
2026-09-04 [Fix] Add 3D model reference materials to .gitignore
2026-09-04 [Feature] OpenSCAD cartoon TV enclosure with per-part STLs
    [antenna.stl, button_carrier.stl, front_shell.stl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]
2026-09-04 [Feature] Assembly view toggles and cutaway planes for the TV model
    [simpsons_tv.scad]
2026-09-04 [Fix] Set CYD glass height to measured 3.9 mm and regenerate STLs
    [antenna.stl, button_carrier.stl, front_shell.stl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]
2026-09-04 [Fix] Attach the front shell lip to the wall, 3.0 mm pilots, filleted bosses, STL shell check
    [antenna.stl, button_carrier.stl, front_shell.stl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]
2026-09-04 [Fix] Centre the window on the measured screen, fit the real USB-C breakout, fail export on OpenSCAD warnings
    [antenna.stl, button_carrier.stl, front_shell.stl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]
2026-09-04 [Fix] Speaker flange 3.5 mm and depth 19 mm from the part in hand
    [antenna.stl, button_carrier.stl, front_shell.stl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]
2026-09-04 [Fix] Build standoffs for the 4.5 mm glass measured on the new CYD
    [antenna.stl, button_carrier.stl, front_shell.stl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]
2026-09-04 [Feature] Add ILI9341 inverted-panel envs for the clone boards
2026-09-04 [Fix] Correct DAC channel number in the board header comments
    [cyd_2432s028r.h]
2026-09-05 [Feature] One-piece front shell with a painted 45 degree CRT bezel, window cut to the measured active area
    [antenna.stl, button_carrier.stl, front_shell.stl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]
2026-09-05 [Feature] CRT-shaped screen window: rectangular face opening lofted to a bulged, round-cornered window
    [antenna.stl, button_carrier.stl, front_shell.stl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]
2026-09-05 [Fix] Keep DAC1 off GPIO25 so the touch clock is not driven by the audio driver; log touch transitions
    [audio_out.cpp, input.cpp]
2026-09-05 [Fix] Touch pressure threshold and drop input queued during the static transition
    [input.cpp, main.cpp]
2026-09-05 [Feature] Bench diagnostics: audio queue stats, busy loop, I2S ISR core select, noise probe
    [audio_out.cpp, input.cpp, main.cpp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]
2026-09-05 [Feature] DMA blit: TFT_eSPI DMA with JPEGDEC ping-pong output so SPI transfer overlaps decode
2026-09-05 [Feature] Converter presets fill the 320x240 panel; balanced is 15 fps after the DMA blit measurements
2026-09-05 [Feature] Settings menu (volume, brightness, colours, flip) in NVS, touch coordinates, boot-hold colour fallback
    [input.cpp, main.cpp, settings.cpp]
2026-09-05 [Feature] External I2S amp output (MAX98357A) as a setting, 16-bit PCM audio, converter emits s16 at 22050 Hz
2026-09-05 [Feature] Wiring guide; drop the inverted-panel envs now that inversion is a runtime setting
